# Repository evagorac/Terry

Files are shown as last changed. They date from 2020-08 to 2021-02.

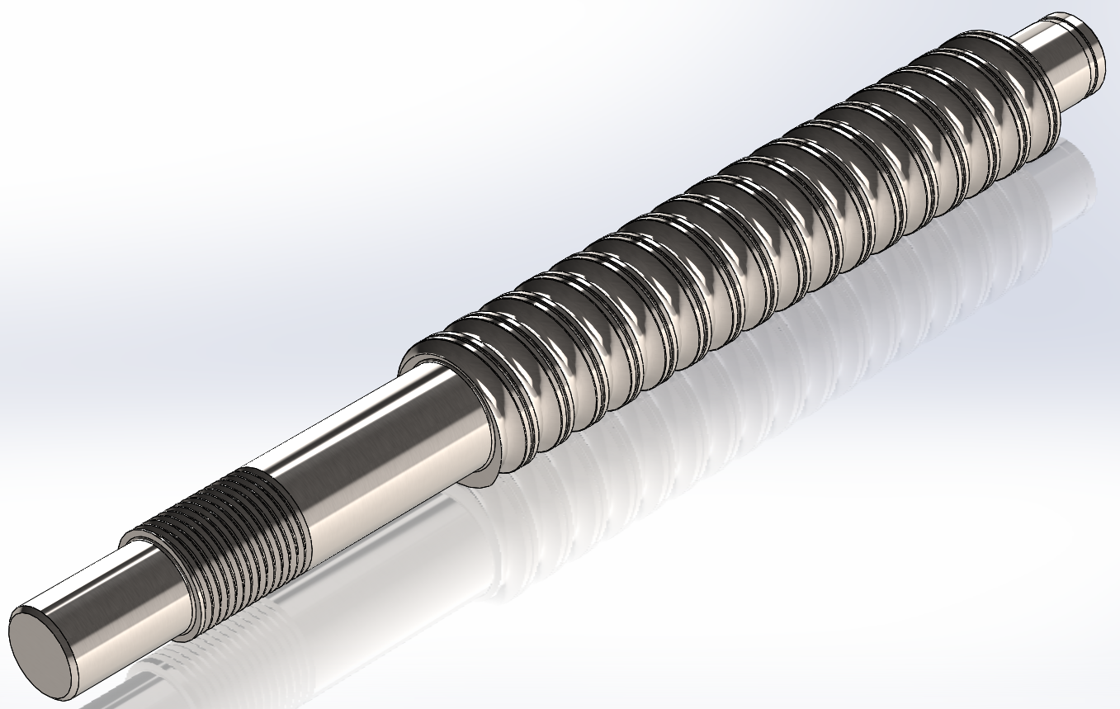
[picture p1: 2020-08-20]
Parts/1605 Screws/SFU1605-150.bmp

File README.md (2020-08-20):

## TERRY

Here is a project I worked on during the summer of 2020.

Terry is a 6 dof spherical robot arm that is capable of visiting any position and orientation in space within the arm's reach.  When completely vertical, Terry is just over 50" tall.  This repository encapsulates the CAD modeling done while designing the robot arm.

Nested within this repo is a submodule called TBrain where I plan to implement the math / matrix transformations for an analytical ikine solution from scratch.  This is where my work will be mostly focused now that summer 2020 is coming to a close and I have nearly finished the physcial construction of Terry.  Terry was made from readily available materials like sheet metal, box tubing, 3d printer filament, and over the counter components.  All the machining was done either by hand or with the CNC router I made a while back in high school.

I have no plans to use Terry for commerical purposes.

GitHub Logo

More images found in https://github.com/evagorac/Terry/tree/master/Pictures

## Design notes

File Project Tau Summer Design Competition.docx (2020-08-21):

Project Tau Summer Design Competition 2020

Christopher Evagora ‘23

This summer I have been designing my own 6 degree of freedom spherical robot arm I named Terry. Robot arms with 6 dof are very popular in modern factories that require high precision and repeatability such as in car manufacturing plants, though they are also extremely popular in robotics as they are a great platform to maneuver and manipulate objects in 3d space. This project seemed like a great idea to pursue because it could enable me to do robotics projects in the future that require such a setup, and because 6 dof robot arms are the coolest. My plan is not only to design, but to build, wire, and code the robot from scratch. Something unique about my design might be the ball screws that drive j2 and j3 with push rods instead of connecting the output of a motor shaft to the axis of rotation. I did this to remove as much backlash in j2 and j3 without the need for super expensive harmonic / cycloidal gearboxes that are standard in most industrial robot arms. I also implemented a differential in j5 and j6 to allow j6 to rotate continuously.

Here is a picture of Terry from solidworks along with the underlying skeleton sketch I will base the kinematic model on:

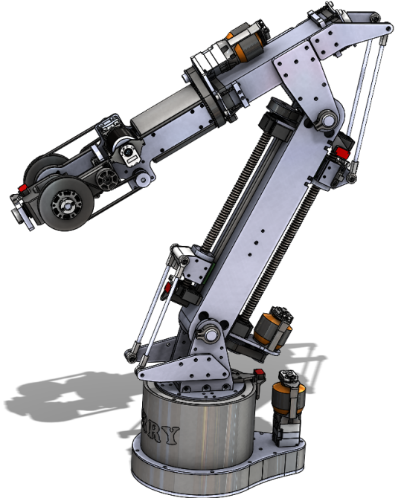
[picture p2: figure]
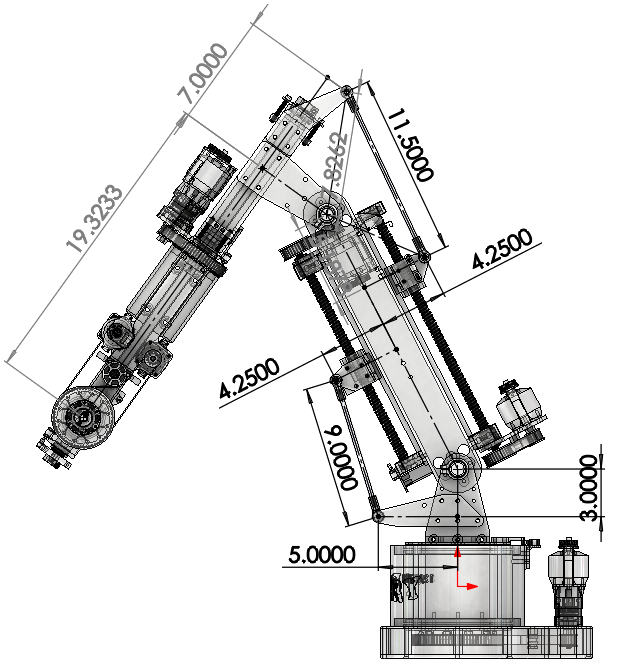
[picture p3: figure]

At their core, robot geometries are simply a series of mechanical joints that rotate. To deconstruct a robot’s underlying kinematic model, a standard set forth by Denavit and Hartenberg called DH parameters can be used to describe the joint transformations from one joint to the next. Because the robot is spherical, loosely meaning that joints 4,5, and 6 act on a single point, I plan to derive an analytical solution to the inverse kinematic model. A kinematic model that applies to Terry and follows the DH convention is as follows:

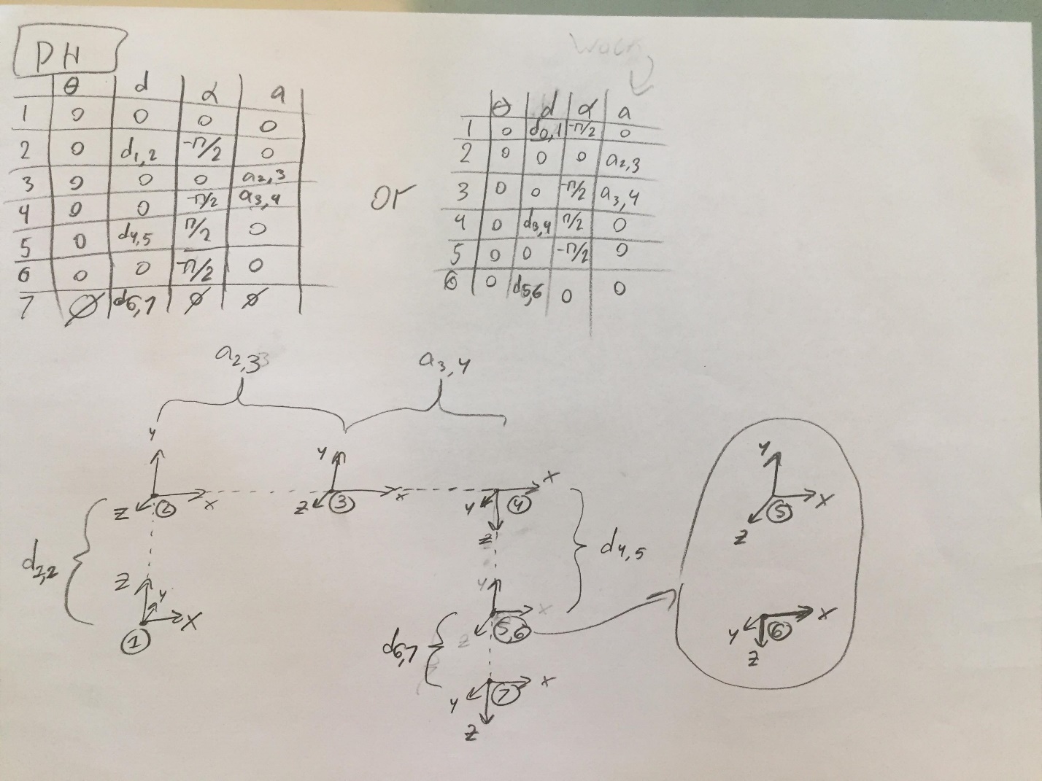
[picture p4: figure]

All of this math plus other stuff I did not write about or document will be extremely necessary when it is implemented, though I have eaten up nearly all of the summer with the design and assembly of Terry. This short description is by no means complete, and more progress will surely be made in the coming months following the end of this summer, so make sure to watch for activity on my github page where all of this will be uploaded. A secondary repository called TBrain is where the code for the robot will be maintained.

>>> https://github.com/evagorac/Terry <<<

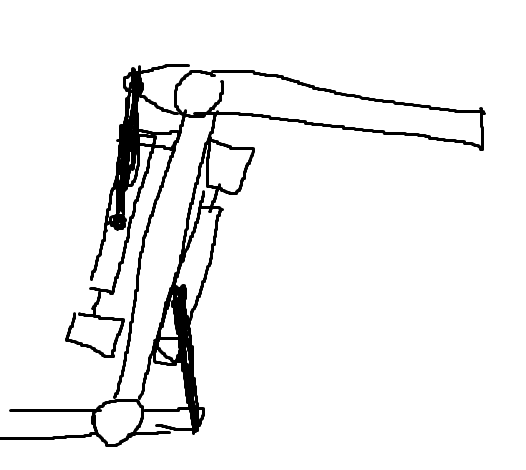
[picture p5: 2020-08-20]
Ideas/BrutonVariant.png

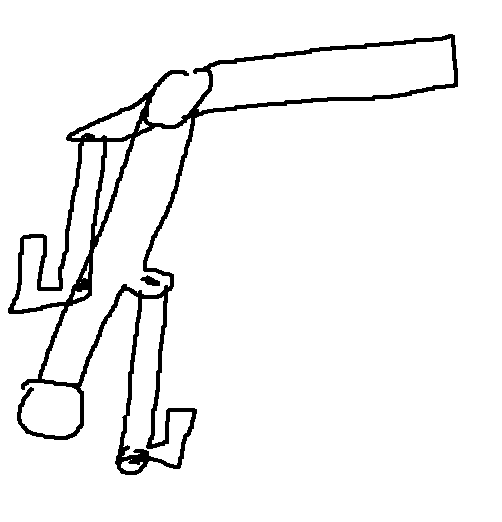
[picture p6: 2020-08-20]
Ideas/LinActuator.png

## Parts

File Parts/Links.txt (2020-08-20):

BallScrew:
https://www.amazon.com/Befenybay-SFU1605-Diameter-Standard-Machining/dp/B07TFF4YSF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
Turntable:
https://www.ebay.com/i/114180632407?itemid=114180632407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
LeadNut:
https://www.servocity.com/8mm-4-start-hub

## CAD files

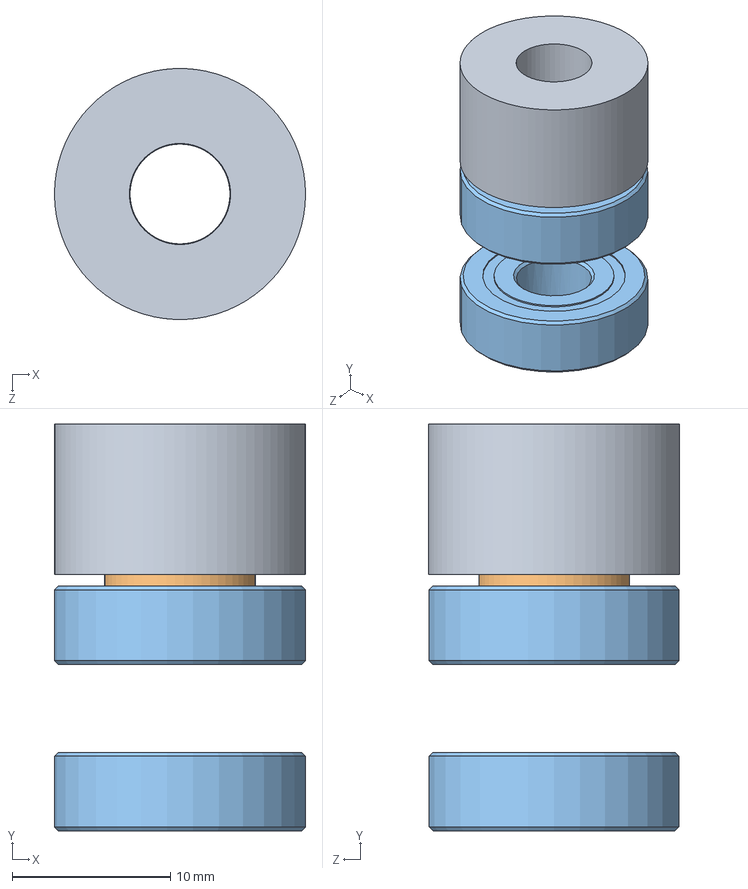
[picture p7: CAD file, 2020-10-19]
Assemblies/TensionPillarJ3.sldasm
15.9 x 25.7 x 15.9 mm
92510A774_ALUM UNTHRD SPACER-1
98019A228_MIL SPEC. 300 SERIES SS FLAT WASHER
60355K701_BALL BEARING x 2

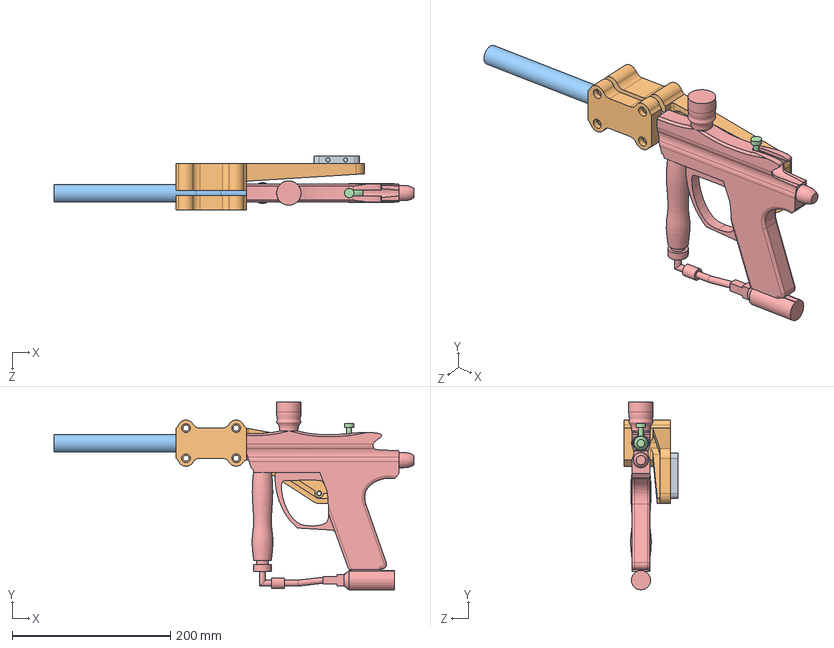
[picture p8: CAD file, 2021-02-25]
Parts/effector.SLDASM
454.7 x 237.2 x 68.1 mm
Bridge^effector
Barrel.step
Delarin Bolt.step
Marker.step

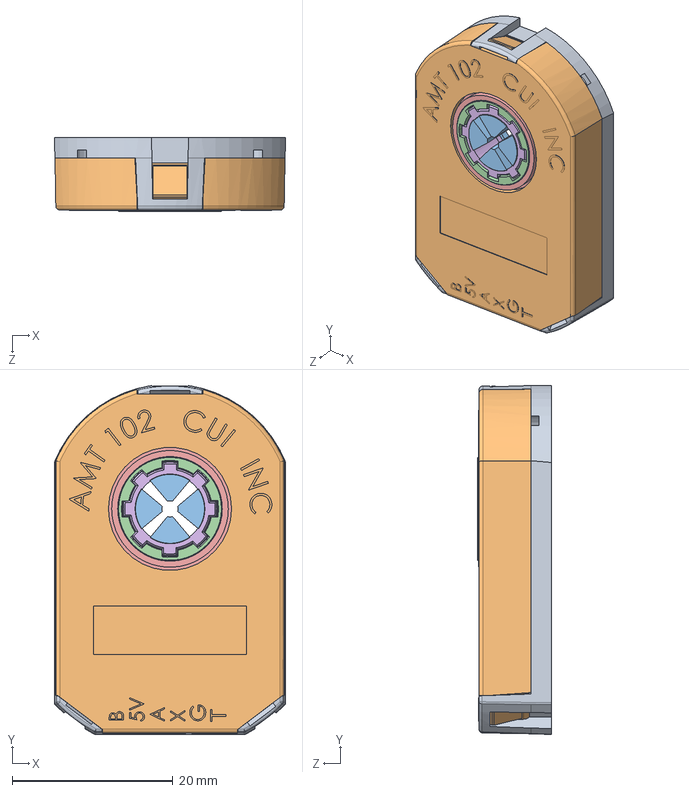
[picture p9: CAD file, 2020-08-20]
Parts/Encoders/CUI_DEVICES_AMT102-0048-N2000-S.SLDASM
28.8 x 43.4 x 9.15 mm
AMT-102-Base-REV-K.step
AMT-102-Top-Cover-REV-H.step
AMT-Sleeve-REV-D_ 2 mm.step
AMT-Hub-Top-REV-D1.step
AMT-Hub-Bottom-REV-B.step
AMT10X-Shaft-Adaptor-REV-E.step
Receiver-board.step
Rotor-board-REV F.step
Transmitter-board AMT10_AMT-102.step

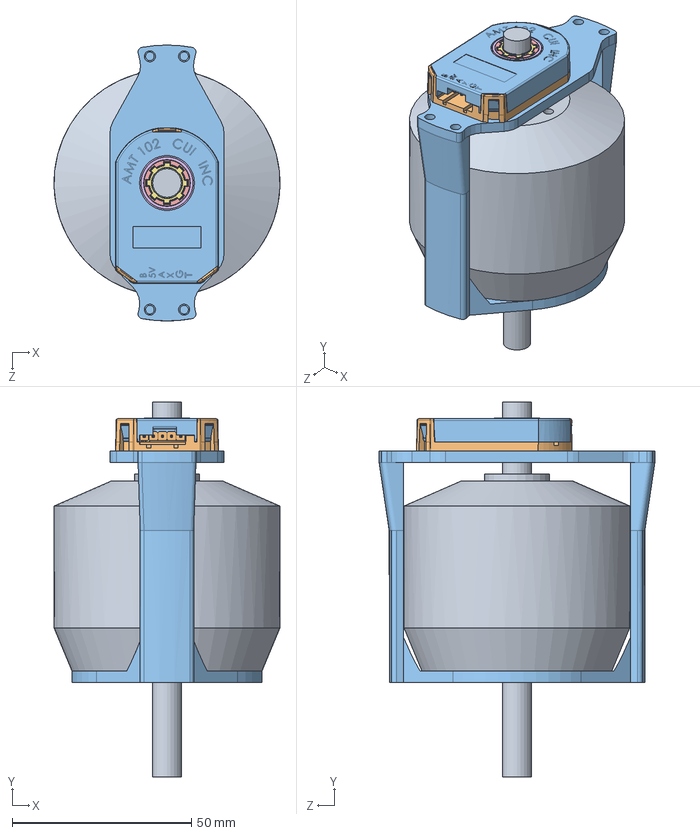
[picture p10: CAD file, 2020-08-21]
Parts/Motors/192kvMotorEncoded.SLDASM
63.0 x 104.5 x 76.9 mm
BetterKEDA
AMT-102-Base-REV-K.step
AMT-102-Top-Cover-REV-H.step
AMT-Sleeve-REV-D_ 2 mm.step
AMT-Hub-Top-REV-D1.step
AMT-Hub-Bottom-REV-B.step
AMT10X-Shaft-Adaptor-REV-E.step
Receiver-board.step
Rotor-board-REV F.step
Transmitter-board AMT10_AMT-102.step
Body^192kvMotorEncoded

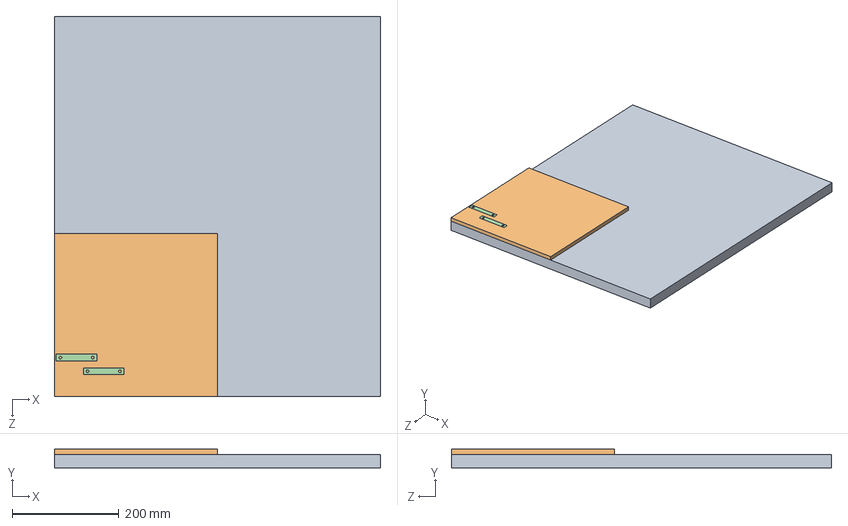
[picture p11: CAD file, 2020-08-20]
Plates/ThreeEighths/retainers.SLDASM
609.6 x 34.9 x 711.2 mm
Bed^retainers
Stock^retainers
FrontRetainer x 2
RearRetainer x 2

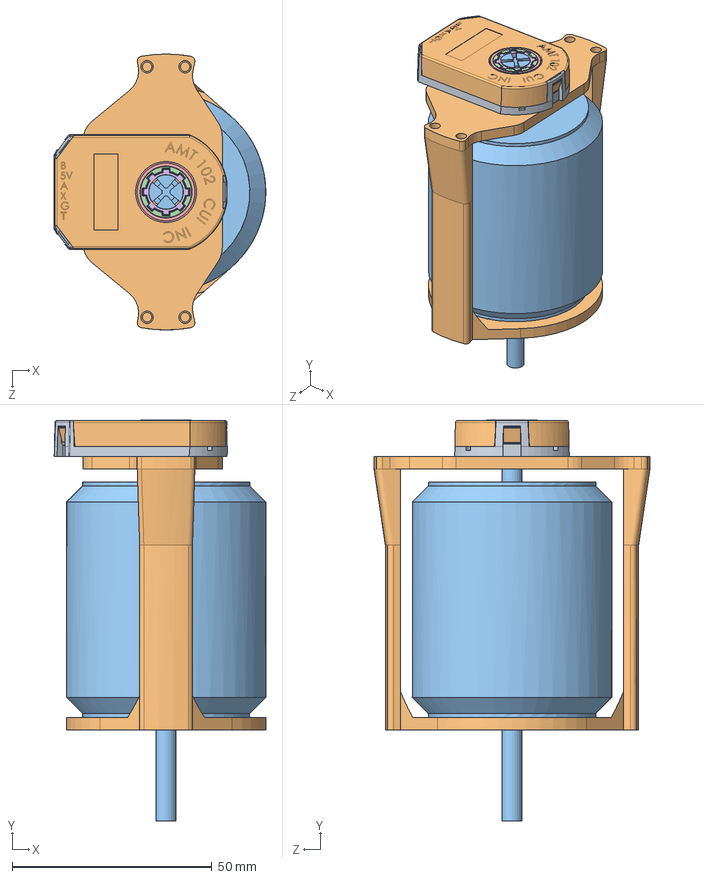
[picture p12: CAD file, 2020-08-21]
Parts/Motors/380kvMotorEncoded.SLDASM
53.0 x 100.5 x 69.2 mm
AMT-102-Base-REV-K.step
AMT-102-Top-Cover-REV-H.step
AMT-Sleeve-REV-D_ 2 mm.step
AMT-Hub-Top-REV-D1.step
AMT-Hub-Bottom-REV-B.step
AMT10X-Shaft-Adaptor-REV-E.step
Receiver-board.step
Rotor-board-REV F.step
Transmitter-board AMT10_AMT-102.step
Body^380kvMotorEncoded
PROPDRIVE v2 5060 380KV Brushless Outrunner Motor

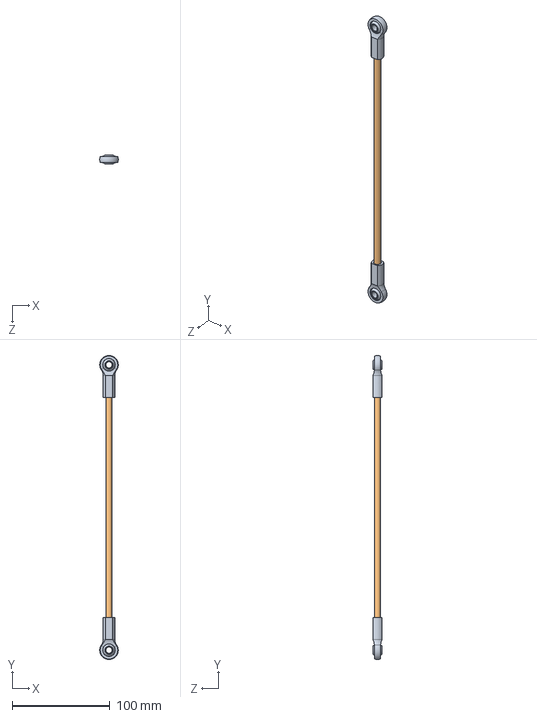
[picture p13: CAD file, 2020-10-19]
Parts/Rods/J3Rod.sldasm
19.0 x 311.1 x 9.53 mm
60645K321_STEEL BALL JOINT ROD END x 2
90322A660_ROD1

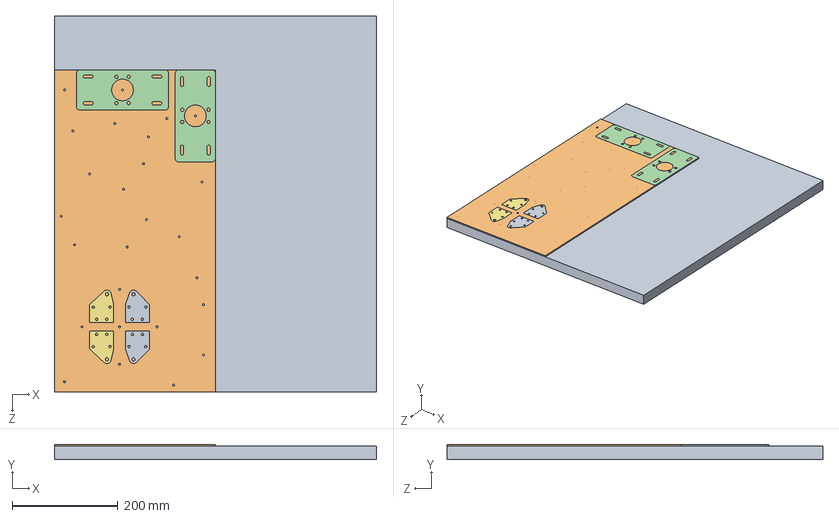
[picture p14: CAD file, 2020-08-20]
Plates/Eighth/eigthcut.SLDASM
609.6 x 28.6 x 711.2 mm
Bed^eigthcut
Stock^eigthcut
BasePlate
Bendy x 2
CarriagePlate x 2
PulleySupportPlate
SidePlate2 x 2
WristSidePlate x 2
SidePlate1fix x 2

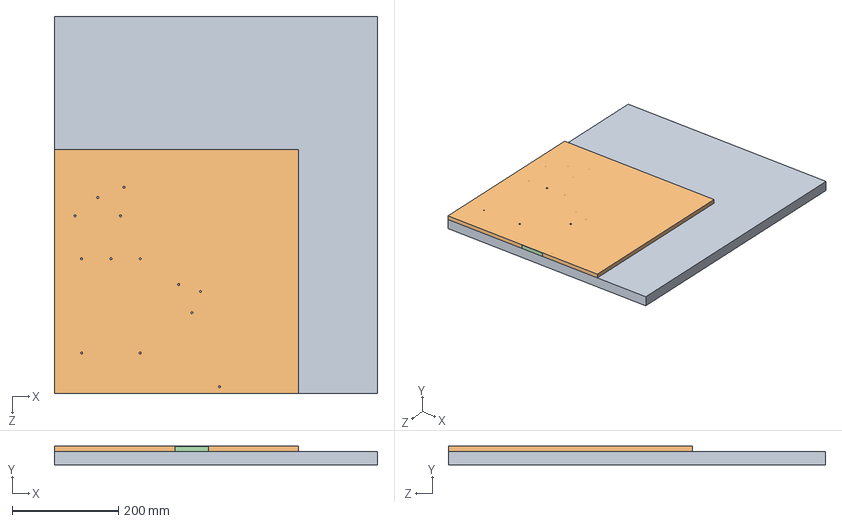
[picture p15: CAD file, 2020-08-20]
Plates/ThreeEighths/threeeighthcut.SLDASM
609.6 x 35.7 x 711.2 mm
Bed^threeeighthcut
Stock^threeeighthcut
HandPlate
SidePlate x 2
SideTurretPlate x 2
TopBrace
WristHub x 2

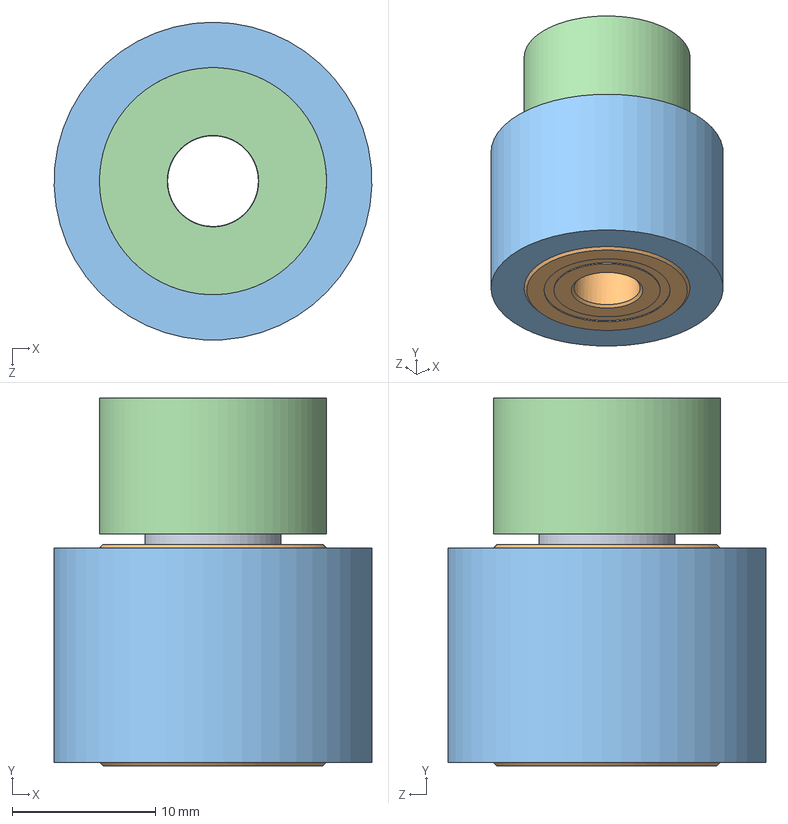
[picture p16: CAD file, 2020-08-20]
Assemblies/TensionPillarJ1.sldasm
22.2 x 25.7 x 22.2 mm
98019A228_MIL SPEC. 300 SERIES SS FLAT WASHER
60355K701_BALL BEARING x 2
Roller^TensionPillarJ1
375spacer

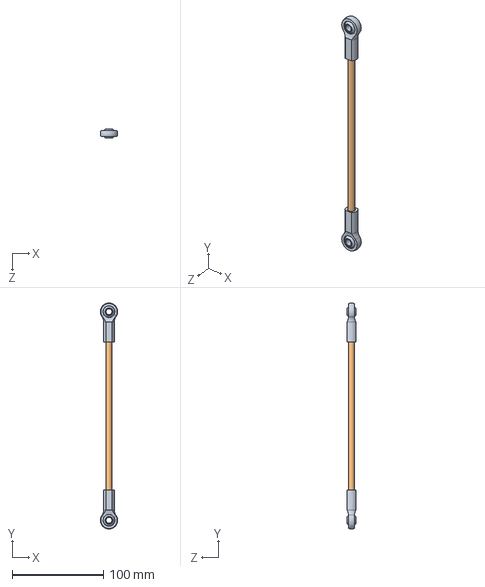
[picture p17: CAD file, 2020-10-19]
Parts/Rods/J2Rod.sldasm
19.0 x 247.6 x 9.53 mm
60645K321_STEEL BALL JOINT ROD END x 2
90322A660_ROD2

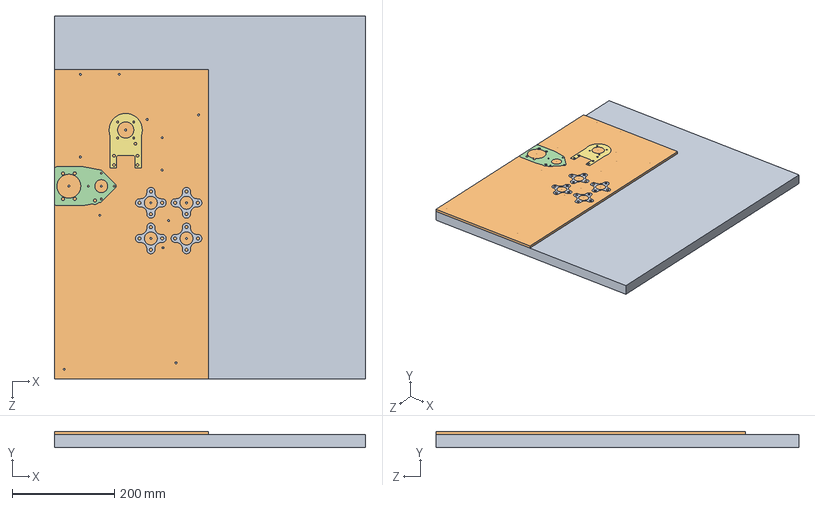
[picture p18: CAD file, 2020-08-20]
Plates/Quarter/quartercut.SLDASM
609.6 x 31.8 x 711.2 mm
Bed^quartercut
Stock^quartercut
BackSidePlate x 2
J4MotorPlate
PivotPlate x 2
Sole
Copy of J2Plate^quartercut
Copy of J3Plate^quartercut
ShaftSupp^Shoulder x 4

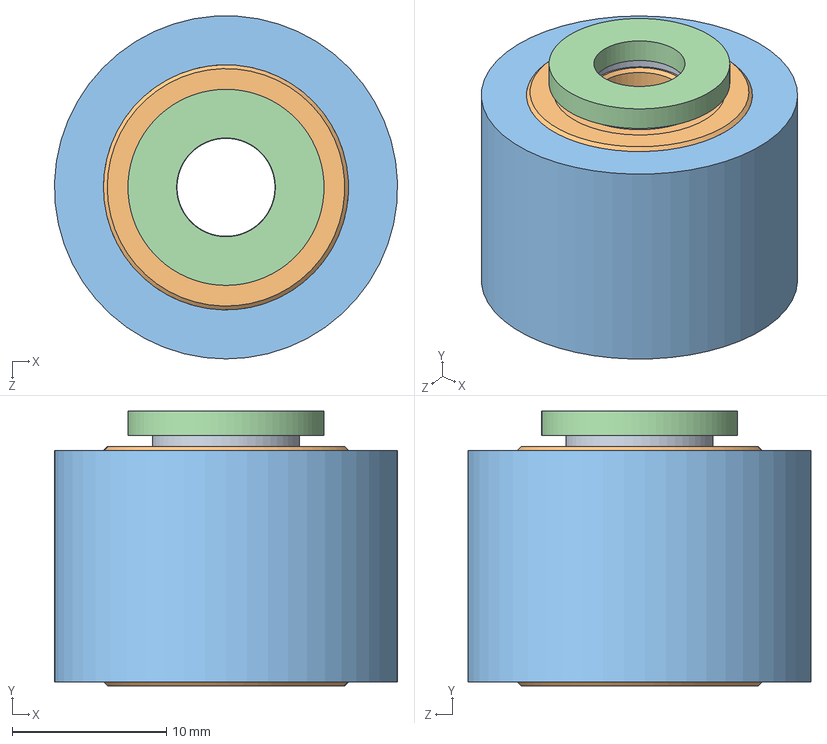
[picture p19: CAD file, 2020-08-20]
Assemblies/TensionPillarJ56.sldasm
22.2 x 17.8 x 22.2 mm
98019A228_MIL SPEC. 300 SERIES SS FLAT WASHER
60355K701_BALL BEARING x 2
Roller^TensionPillarJ56
92510A398_ALUM UNTHRD SPACER

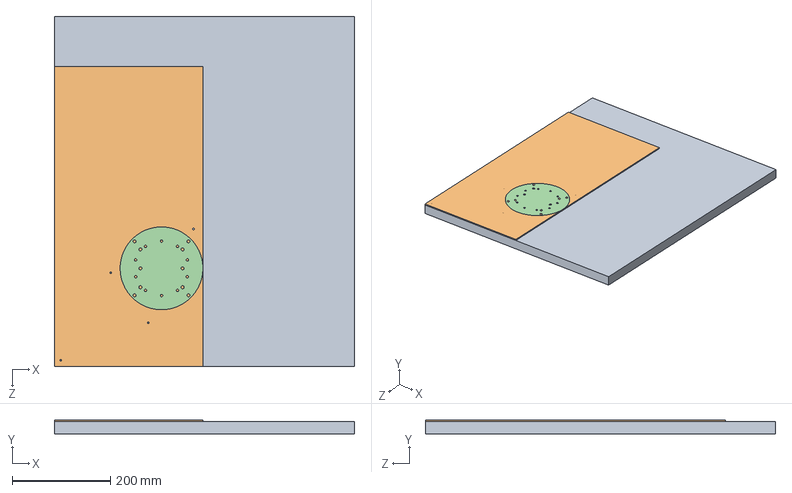
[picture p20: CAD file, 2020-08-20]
Plates/Eighth/eigthcut2.SLDASM
609.6 x 28.6 x 711.2 mm
Bed^eigthcut2
Stock^eigthcut2
Copy of TopTurretPlate^eigthcut2
Copy of BotTurretPlate^eigthcut2

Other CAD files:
Assemblies/TensionPillarJ2.sldasm
Assemblies/CorruptedShoulder.SLDASM
Assemblies/gasSpring.sldasm
Assemblies/MirrorgasSpring.sldasm
Assemblies/4138T538_GAS SPRING.SLDPRT
Assemblies/TensionPillarJ4.sldasm
Assemblies/gasSpring2.sldasm
Backups/T05252020/6061K602_HARDENED PRECISION STEEL SHAFT.SLDPRT
Backups/T05252020/8in.SLDPRT
Backups/T05252020/Base.SLDASM
Backups/T05252020/EXTENDED SHAFT KEDA 56-63 195KV Brushless Outrunner 6S 1500W v2 v2.SLDPRT
Backups/T05252020/EXTENDED SHAFT KEDA 56-63 195KV Brushless Outrunner 6S 1500W v2 v2.step
Backups/T05252020/Forearm.SLDASM
Backups/T05252020/Shoulder.SLDASM
Backups/T05252020/TerryOLD.SLDASM
Backups/T05262020/5909K310_THRUST NEEDLE-ROLLER BEARING.SLDPRT
Backups/T05262020/5909K330_THRUST NEEDLE-ROLLER BEARING.SLDPRT
Backups/T05262020/5909K440_THRUST NEEDLE-ROLLER BEARING.SLDPRT
Backups/T05262020/5909K460_THRUST NEEDLE-ROLLER BEARING.SLDPRT
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

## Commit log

2020-08-21 fixed tolerance
    [192kvMotorEncoded.SLDASM, 380kvMotorEncoded.SLDASM]
2020-09-07 better wiring
2020-10-19 fixed some errors, thickened bottom plate
    [90322A660_ROD1.sldprt, 90322A660_ROD2.sldprt, J1Pulley.SLDPRT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]
2020-12-14 fixed insert tolerances
    [94459A180_BRASS HEAT-SET INSERT FOR PLASTIC.SLDPRT, Box.sldprt, SidePlate1fix.sldprt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]
2020-12-29 updated wrist
    [HandPlate.sldprt]
2021-02-25 added marker
    [Box.sldprt, HandPlate.sldprt, J3MGN12R.sldprt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]
